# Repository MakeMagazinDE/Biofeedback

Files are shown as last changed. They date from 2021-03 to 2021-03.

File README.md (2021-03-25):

GitHub Logo

Maker Media GmbH

***

# Biofeedback für den Maker

### In diesem Artikel aus Make 2/21 zeigen wir, wie Sie mithilfe einfacher Elektronik und einem Arduino Nano Ihren Herzschlag und die Respiratorische Sinusarrhythmie (RSA) darstellen und trainieren können, um Ihr Herz zu trainieren und sich zu entspannen.

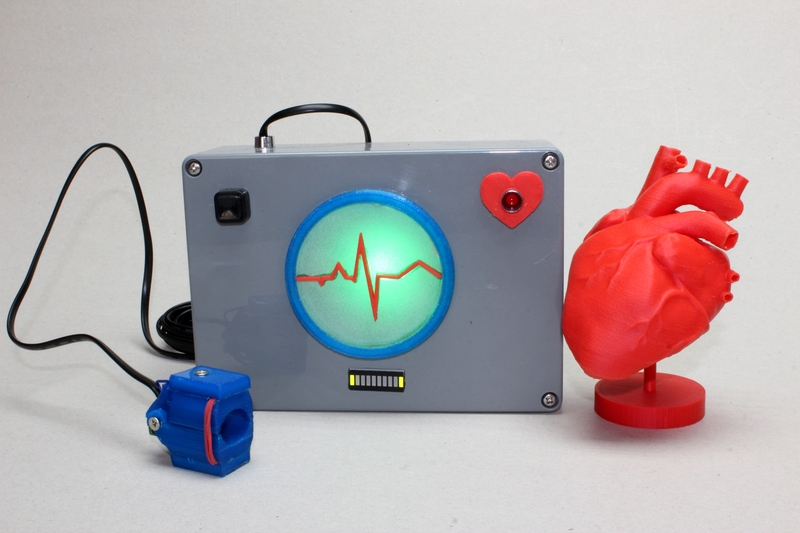
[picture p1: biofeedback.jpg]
 
 
Hier finden Sie den Arduino Code und die 3D-Druckvorlagen.

Den vollständigen Artikel mit der Bauanleitung gibt es in der [Make-Ausgabe 2/21 ab Seite 48](https://www.heise.de/select/make/2021/2/2030713551620947076). 

### Materialliste

| **Anzahl** | **Bezeichnung** |
| :--- | --- |
| 1 | Gehäuse z.B. 170 mm X 120mm X 55 mm |
| 1 | Arduino Nano |
| 1 | 10 Segment LED Bar |
| 1 | 10 mm RGB LED |
| 1 | 5mm LED rot |
| 1 | Batteriefach für 6 AA Akkus |
| 1 | Lochrasterplattine |
| 1 | IC TL072 |
| 1 | IR-LED 940 nm |
| 1 | IR Photodiode 940 nm |
| 1 | Elko 10 uF |
| 1 | Kondensator 100 nF |
| 1 | Kondensator 10 nF |
| 1 | Widerstand 120 Ω |
| 1 | Widerstand 56 K |
| 2 | Widerstand 220 K |
| 1 | Widerstand 2,2 M |
| 1 | Widerstand 4,7 M |
| 1 | Widerstand 10 K |
| 1 | Widerstand 3,3 K |
| 1 | Widerstand 150 k |
| 10 | Widerstand 470 Ω |
| 1 | Widerstand 220 Ω |
| 2 | Widerstand 100 Ω |

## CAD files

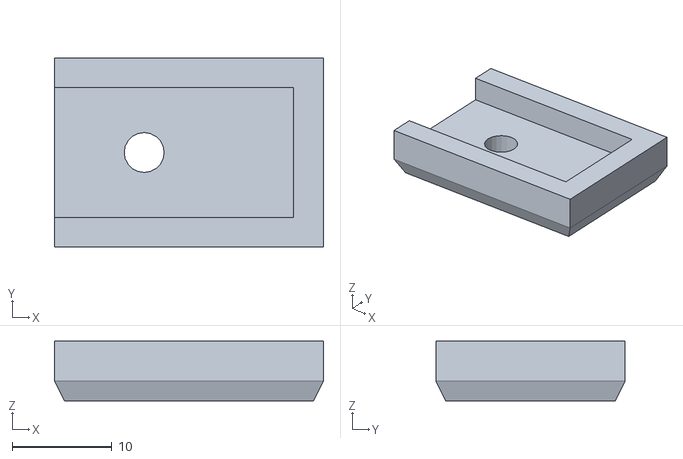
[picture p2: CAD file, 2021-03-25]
cad/Deckel.stl
27.0 x 19.0 x 6.00

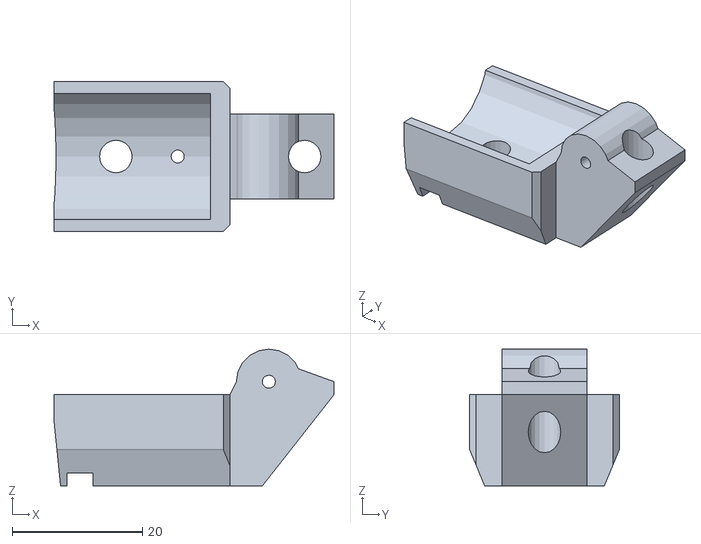
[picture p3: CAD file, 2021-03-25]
cad/Pulsmesser_oben.stl
43.0 x 23.0 x 21.0

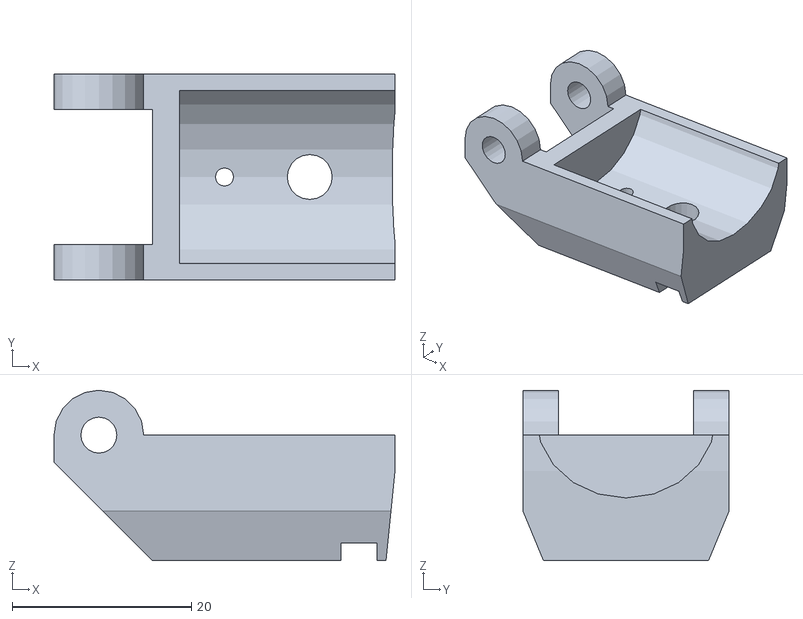
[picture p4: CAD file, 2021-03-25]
cad/Pulsmesser_unten.stl
38.0 x 23.0 x 19.0

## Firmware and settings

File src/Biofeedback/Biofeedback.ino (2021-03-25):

///////////////////////////////////////////////////////////////////////////////////
// Biofeedback
// von Ulrich Schmerold
// 09/2020
////////////////////////////////////////////////////////////////////////////////////
#include "LED.h"

unsigned int value;       // Wert vom Pulssensor
const int Abstand = 6;    // Abstand von Puls ein - Puls aus
unsigned long timer;
unsigned long duration = 700;  // Abstand (Zeit) zwischen zwei Pulssequenzen. Wert wird später angepasst.
byte state = 0;

float Output;         // Ergebnis der Mittelwert-Rechnung.
float Oldvalue = 700; // wird durch Mittelwertberechnung angepasst
const float n = 0.98; // Wert für die Berechnung vom Gleitenden Mittelwert (n < 1)


int RSA;  //Respiratorische SinusArrhythmie 
// die folgenden vier Variablen werden zur Berechnung eines RSA aus einer Atemsequenz (Aus + Einatmung) benötigt
long T_Ein = 0L;
long T_Aus = 0L;
 int N_Ein = 0;
 int N_Aus = 0;
 
void setup() {
  Serial.begin(9600);
  pinMode( A0, INPUT );     // Pin, an dem der Pulssensor angeschlossen ist
  SetupLED();               // Initialisierung aller Variablen für die LED Anzeigen (LED.h)
  digitalWrite(RGBr, HIGH); 
}

void loop() {
  
  int z = Atmung(); // LED-Balkenanzeige laufen lassen  
  
  //**************** Messung Pulssignal ***********************
    
  value = analogRead(A0);
  
  //***************** gleitender Mittelwert (Lowpass-Filter )***************
  
  Output = Oldvalue * n + value * (1 - n); // wobei n < 1
  Oldvalue = Output;
  
  //************************************************************************
  if (value > (Output + Abstand))
  {
    if (state == 0) { // Pulsschlag erkannt
      state = 1;
      duration = millis() - timer;
      timer = millis();
      digitalWrite(LEDPuls, HIGH); // Puls LED einschalten
      
      // ***************** Ausgabe der Dauer einer Pulssequenz für den Arduino Serial Plotter
      // if ((duration >750) && (duration<900))   Serial.println(duration);
      
      //****************** hier wird die Respiratorische SinusArrhythmie (RSA) aus einer Atemsequenz ermittelt ********
      if ( z > 0 && z < 10) {  // Einatmung
        N_Ein++;
        T_Ein = T_Ein + duration;
      }
      if ( z > 10 && z <= 19) { // Ausatmung
        N_Aus++;
        T_Aus = T_Aus + duration;
      }
      if (z == 0){ // eine Atemsequenz abgeschlossen
        RSA = ((T_Aus / N_Aus) - (T_Ein / N_Ein));
        if (RSA >= 0) { 
          digitalWrite(RGBr, LOW);
          digitalWrite(RGBg, HIGH);
        }
        if (RSA < 0){
          digitalWrite(RGBg, LOW);
          digitalWrite(RGBr, HIGH);
        }
        T_Aus = 0L;
        T_Ein = 0L;
        N_Ein = 0;
        N_Aus = 0;
      }
      //**************************************************************************
    }
  }
  if (state == 1) {
    if  (value < (Output )) {
      state = 0;
      digitalWrite(LEDPuls, LOW);  //Puls LED auschalten
    }
  }

  // *************** Testausgabe der Werte *****************
    Serial.print(value);

    Serial.print(","); Serial.print(Output+Abstand);
    Serial.print(","); Serial.print(Output);

    Serial.println(); 

  //*************************************************************
}

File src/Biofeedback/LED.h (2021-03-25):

const byte LEDPuls = 12; // LED blinkt im Tackt vom Puls

const byte RGBg = 11;   //Große LED grün 
const byte RGBr = 10;   //Große LED rot

const byte Balken1 = 2;
const byte Balken2 = 3;
const byte Balken3 = 4;
const byte Balken4 = 5;
const byte Balken5 = 6;
const byte Balken6 = 7;
const byte Balken7 = 8;
const byte Balken8 = 9;

byte z = 0;
unsigned long t = millis();
const unsigned long f = 60000 / 6 / 19; // Zeit pro Atemphase ==> 6 Atemzüge pro Minute  ==> Millisekunden (6000) / Atemzüge (6) / Phasen Balkenanzeige (19)

int zz = 3;

void SetupLED()
{
  pinMode( LEDPuls, OUTPUT );
  
  pinMode( RGBr, OUTPUT );
  pinMode( RGBg, OUTPUT );

  pinMode( Balken1, OUTPUT );
  pinMode( Balken2, OUTPUT );
  pinMode( Balken3, OUTPUT );
  pinMode( Balken4, OUTPUT );
  pinMode( Balken5, OUTPUT );      
  pinMode( Balken6, OUTPUT );  
  pinMode( Balken7, OUTPUT );  
  pinMode( Balken8, OUTPUT );  
}

int Atmung()
{  
  if(millis() - t > f ) {
    switch ( z++ ){
      case 1:
        digitalWrite(Balken1, HIGH);  // Einatmung beginnt
      break;
      case 2:
        digitalWrite(Balken1, LOW);
        digitalWrite(Balken2, HIGH);  
      break;
      case 3:
        digitalWrite(Balken2, LOW);
        digitalWrite(Balken3, HIGH);  
      break;
      case 4:
        digitalWrite(Balken3, LOW);
        digitalWrite(Balken4, HIGH);  
      break;
      case 5:
        digitalWrite(Balken4, LOW);
        digitalWrite(Balken5, HIGH);  
      break;
      case 6:
         digitalWrite(Balken5, LOW);
         digitalWrite(Balken6, HIGH);  
      break;
      case 7:
        digitalWrite(Balken6, LOW);
        digitalWrite(Balken7, HIGH);  
      break;      
      case 8:
        digitalWrite(Balken7, LOW);
        digitalWrite(Balken8, HIGH);  
      break;
      case 9:
           digitalWrite(Balken8, LOW);  
      break;
    
      // ***************   kurze Pause
      
      case 11:
           digitalWrite(Balken8, HIGH);  
      break;    
      case 12:
        digitalWrite(Balken8, LOW);  // Ausatmung beginnt
        digitalWrite(Balken7, HIGH);  
      break;
      case 13:
        digitalWrite(Balken7, LOW);  
        digitalWrite(Balken6, HIGH);  
      break;
      case 14:
        digitalWrite(Balken6, LOW);  
        digitalWrite(Balken5, HIGH);  
      break;
      case 15:
        digitalWrite(Balken5, LOW);  
        digitalWrite(Balken4, HIGH);  
      break;
     case 16:
        digitalWrite(Balken4, LOW);  
        digitalWrite(Balken3, HIGH);  
      break;
     case 17:
        digitalWrite(Balken3, LOW);  
        digitalWrite(Balken2, HIGH);  
      break;
      case 18:
        digitalWrite(Balken2, LOW);  
        digitalWrite(Balken1, HIGH);  
      break;
     case 19:
        digitalWrite(Balken1, LOW);
        z=0;  
      break;      
    }
    t=millis();
  }
  return(z);
      
}
